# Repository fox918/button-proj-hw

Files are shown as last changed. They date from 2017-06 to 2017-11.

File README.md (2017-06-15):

# Hacker Jeopardy Buttons and Mood Lighting Shelf

## Idea

This is a small PCB designed for a NodeMCU v3 to control up to 4 WS2812b LED-Strips.
The goal of the project is to light up hacker jeopardy buttons or to light something with
the ws2812b buttons.

## Considerations:
- care has been taken that at least 2 strips are usable for Lua or Micropython respectively
- There is a jumper to bypass the voltage regulator if the board is directly supplied with 5V

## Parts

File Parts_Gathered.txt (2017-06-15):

== Requirements ==
-12V Power for Matt
-5V for Oliver
-2 Strips for Oliver / 1 for Matt
-1 Button for Oliver

== Power 12V / 5V ==
-Oliver:    Bypass because I got already 5V
-Matt:      12V->5V Linear Regulator
            AZ1117CH-5.0TRG1 in SOT223

== Level Shifter ==
4x Buffer HCT Series, SN74AHCT125DRG4 in SOIC

== Connectors ==
-Oliver: Solder on snap ins
-Matt:   evtl. Mini-XLR

== Proposals ==
SERIES resistor between: Node<->Buffer and Buffer<->Strip
Polyfuse on Input

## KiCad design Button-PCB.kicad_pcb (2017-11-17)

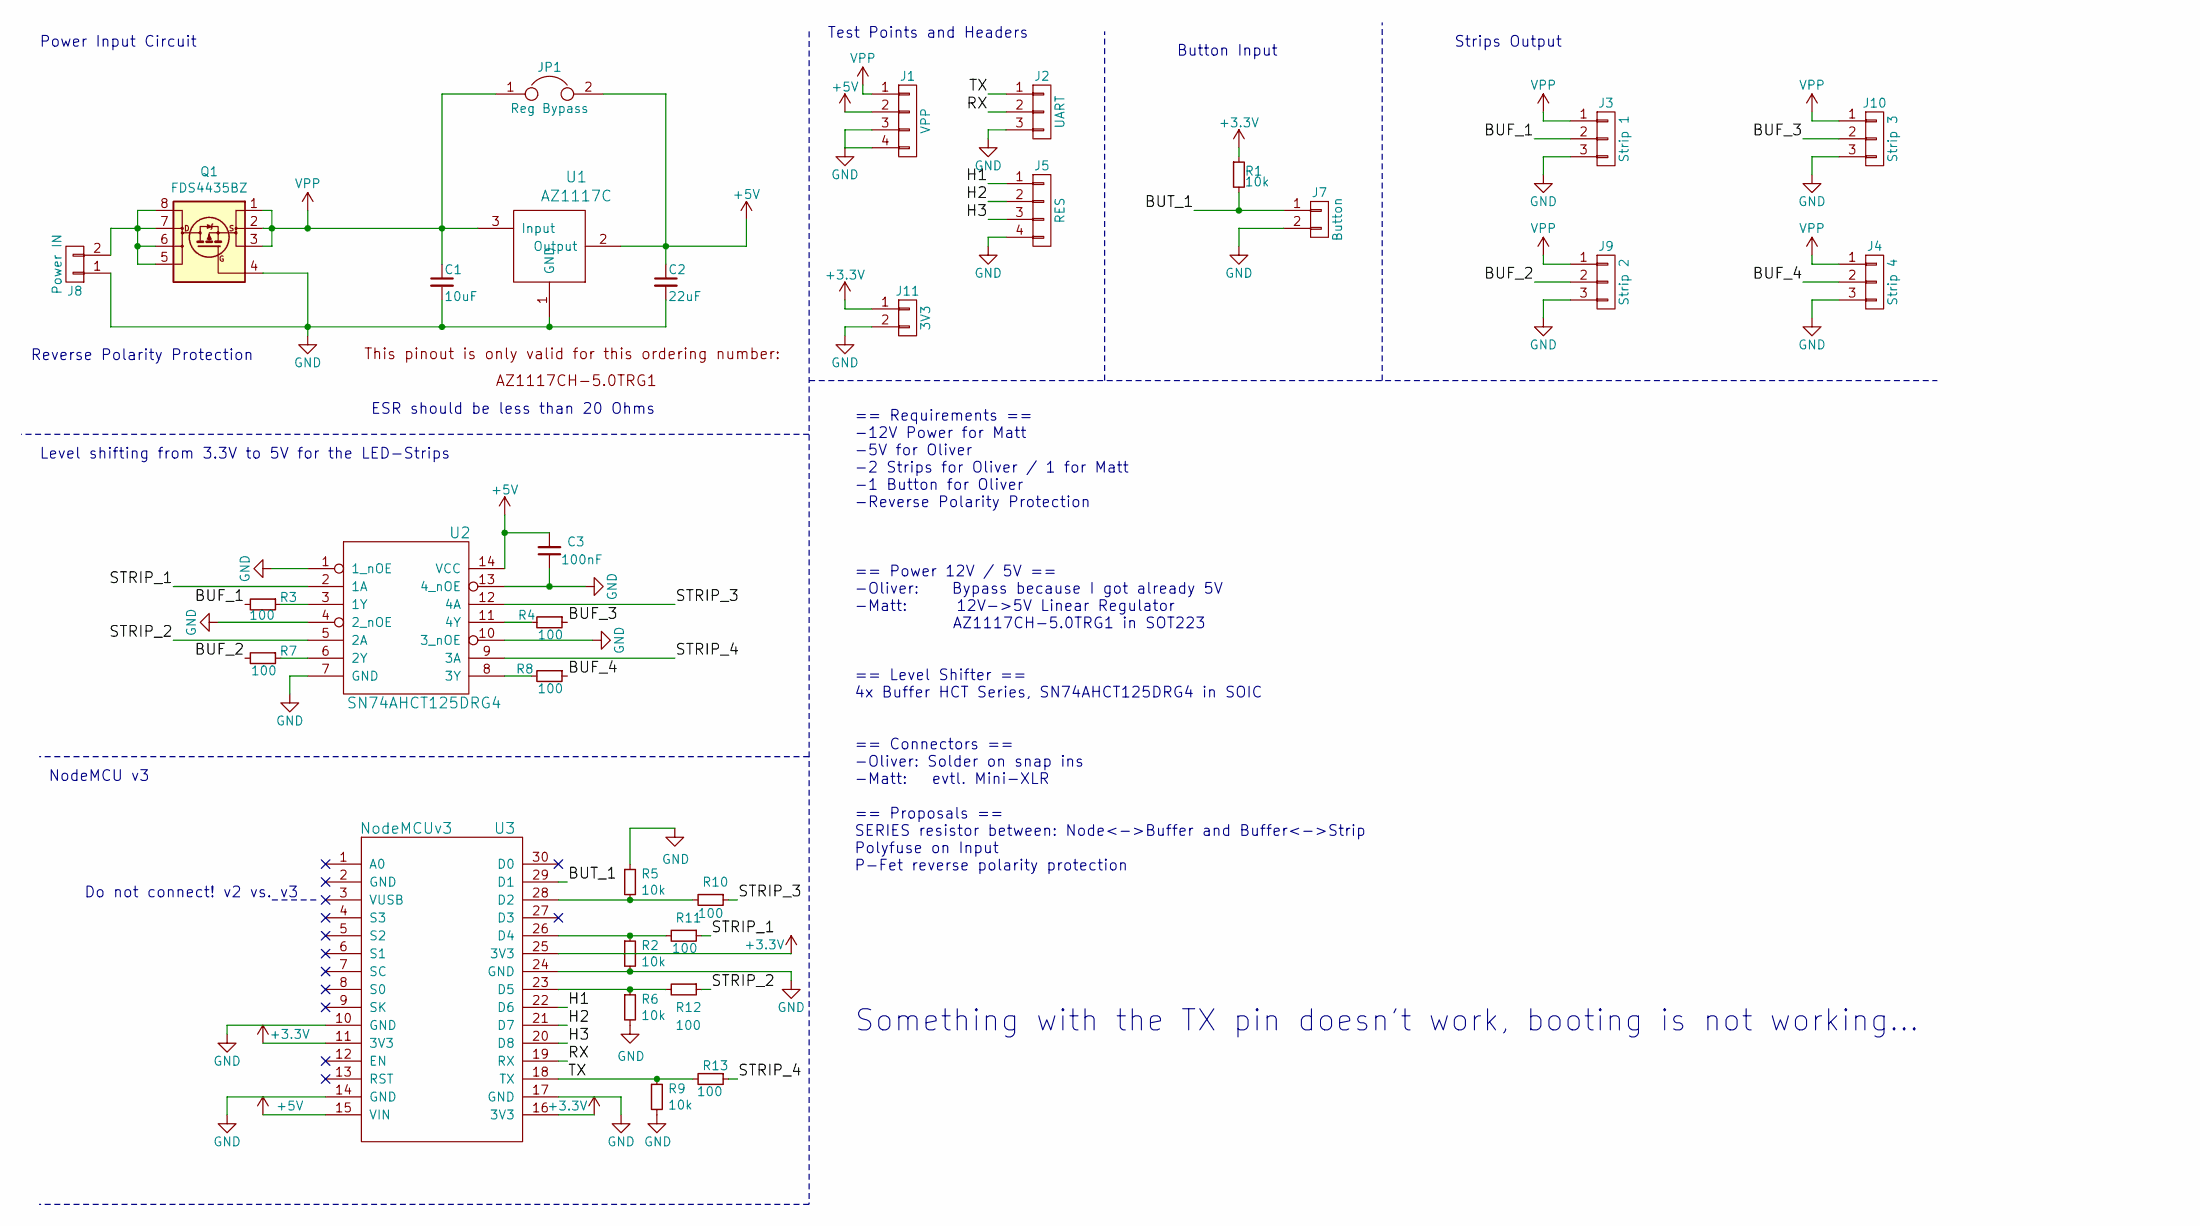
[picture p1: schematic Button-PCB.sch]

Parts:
C1: 10uF; C_0805
C2: 22uF; C_0805
C3: 100nF; C_0805
J1: VPP; Pin_Header_Straight_1x04_Pitch2.54mm
J2: UART; Pin_Header_Straight_1x03_Pitch2.54mm
J3: Strip 1; Pin_Header_Angled_1x03_Pitch2.54mm
J4: Strip 4; Pin_Header_Angled_1x03_Pitch2.54mm
J5: RES; Pin_Header_Straight_1x04_Pitch2.54mm
J7: Button; Pin_Header_Straight_1x02_Pitch2.54mm
J8: Power IN; Pin_Header_Straight_1x02_Pitch2.54mm
J9: Strip 2; Pin_Header_Angled_1x03_Pitch2.54mm
J10: Strip 3; Pin_Header_Angled_1x03_Pitch2.54mm
J11: 3V3; Pin_Header_Straight_1x02_Pitch2.54mm
JP1: Reg Bypass; Pin_Header_Straight_1x02_Pitch2.54mm
Q1: FDS4435BZ; SOIC-8_3.9x4.9mm_Pitch1.27mm
R1, R2, R5, R6, R9: 10k; R_0805
R3, R4, R7, R8, R10, R11, R12, R13: 100; R_0805
U1: AZ1117C; SOT-223-3Lead_TabPin2
U2: SN74AHCT125DRG4; SOIC-14_N
U3: NodeMCUv3; nodemcu_v3

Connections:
+3V3: J11.1, R1.1, U3.11 (3V3), U3.16 (3V3), U3.25 (3V3)
+5V: C2.1, C3.2, J1.2, JP1.2, U1.2 (Output), U2.14 (VCC), U3.15 (VIN)
/BUF_1: J3.2, R3.2
/BUF_2: J9.2, R7.2
/BUF_3: J10.2, R4.1
/BUF_4: J4.2, R8.1
/BUT_1: J7.1, R1.2, U3.29 (D1)
/H1: J5.1, U3.22 (D6)
/H2: J5.2, U3.21 (D7)
/H3: J5.3, U3.20 (D8)
/RX: J2.2, U3.19 (RX)
/STRIP_1: R11.1, U2.2 (1A)
/STRIP_2: R12.1, U2.5 (2A)
/STRIP_3: R10.1, U2.12 (4A)
/STRIP_4: R13.1, U2.9 (3A)
/TX: J2.1, R9.1, R13.2, U3.18 (TX)
GND: C1.2, C2.2, C3.1, J1.3, J1.4, J2.3, J3.3, J4.3, J5.4, J7.2, J8.1, J9.3, J10.3, J11.2, Q1.4 (G), R2.2, R5.1, R6.2, R9.2, U1.1 (GND), U2.1 (1_nOE), U2.4 (2_nOE), U2.7 (GND), U2.10 (3_nOE), U2.13 (4_nOE), U3.10 (GND), U3.14 (GND), U3.17 (GND), U3.24 (GND)
unnamed: J8.2, Q1.5 (D), Q1.6 (D), Q1.7 (D), Q1.8 (D)
unnamed: R3.1, U2.3 (1Y)
unnamed: R4.2, U2.11 (4Y)
unnamed: R7.1, U2.6 (2Y)
unnamed: R8.2, U2.8 (3Y)
unnamed: R5.2, R10.2, U3.28 (D2)
unnamed: R2.1, R11.2, U3.26 (D4)
unnamed: R6.1, R12.2, U3.23 (D5)
VPP: C1.1, J1.1, J3.1, J4.1, J9.1, J10.1, JP1.1, Q1.1 (S), Q1.2 (S), Q1.3 (S), U1.3 (Input)

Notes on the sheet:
== Requirements == -12V Power for Matt -5V for Oliver -2 Strips for Oliver / 1 for Matt -1 Button for Oliver -Reverse Polarity Protection == Power 12V / 5V == -Oliver: Bypass because I got already 5V -Matt: 12V->5V Linear Regulator AZ1117CH-5.0TRG1 in SOT223 == Level Shifter == 4x Buffer HCT Series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
Strips Output
Button Input
Test Points and Headers
ESR should be less than 20 Ohms
Power Input Circuit
Do not connect! v2 vs. v3
Reverse Polarity Protection
Level shifting from 3.3V to 5V for the LED-Strips
NodeMCU v3
Something with the TX pin doesn't work, booting is not working...

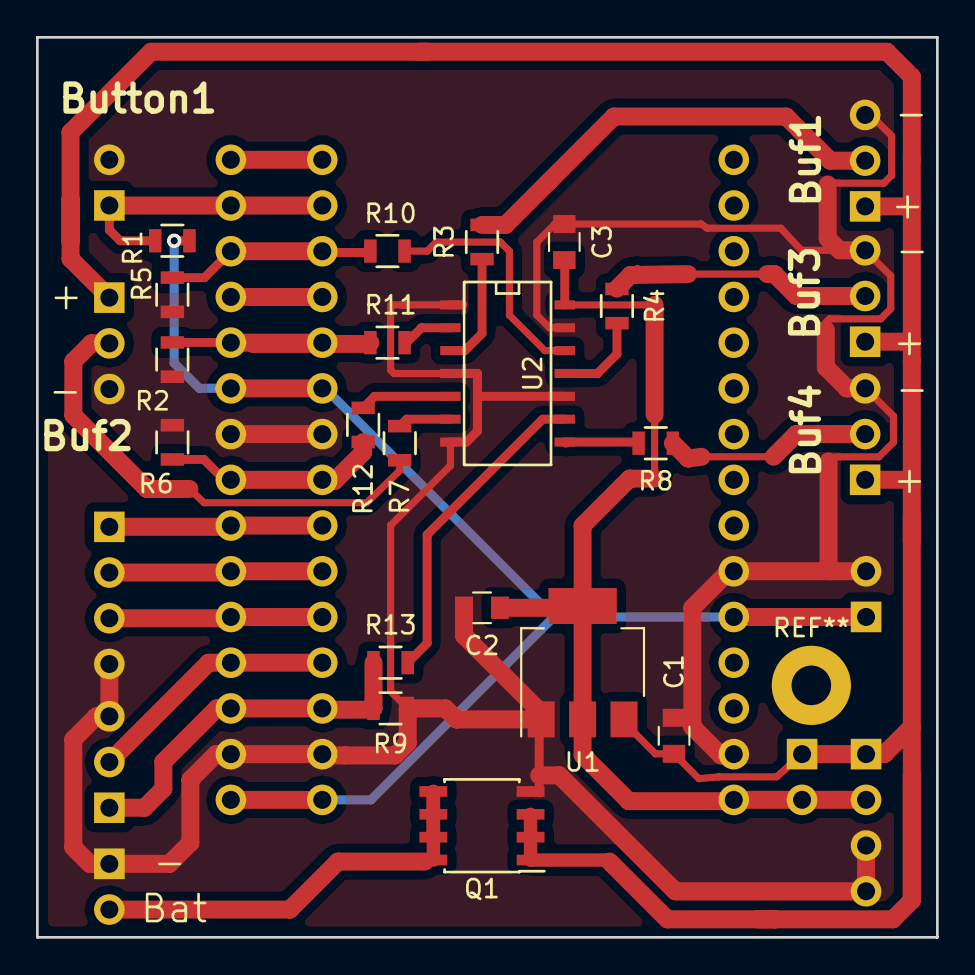
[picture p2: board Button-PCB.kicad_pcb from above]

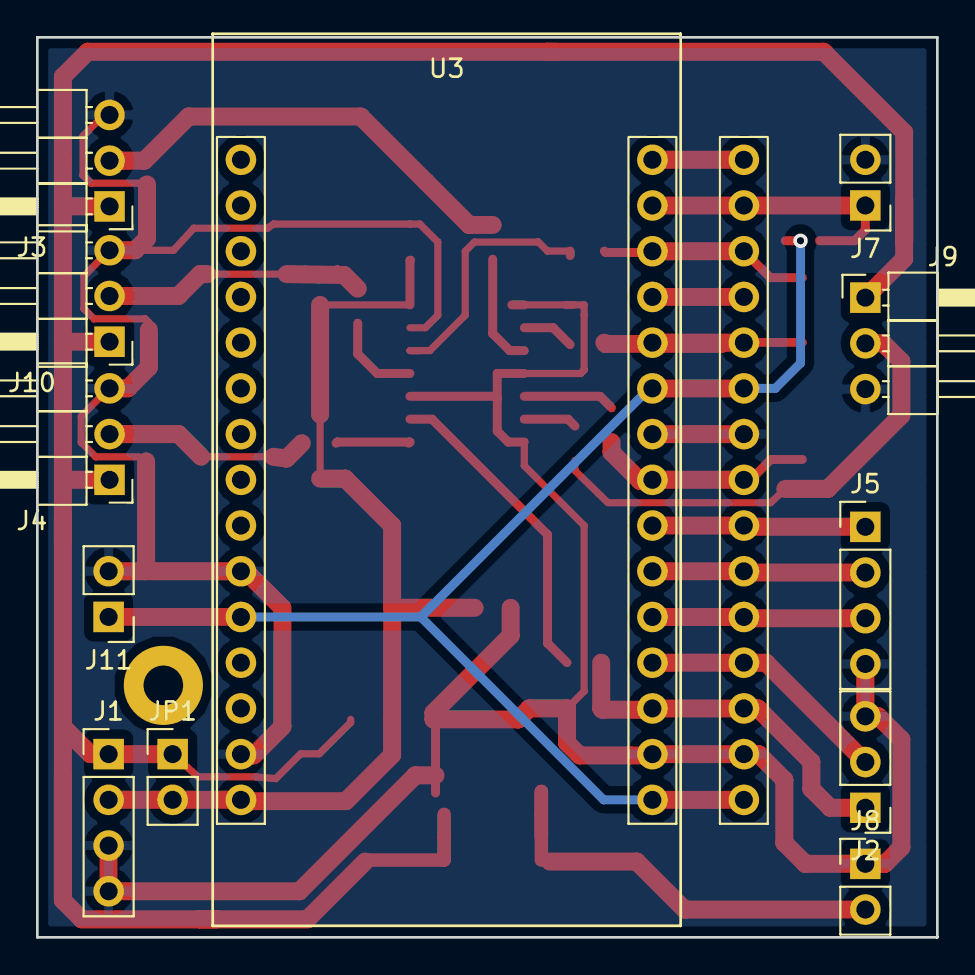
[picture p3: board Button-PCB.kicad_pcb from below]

Board: 2 copper layers, 50.0 x 50.0 mm, 31 parts (12 on the bottom side), 26 nets.

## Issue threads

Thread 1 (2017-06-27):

Improvements

fox918, 2017-06-27:
Thoughts:

- the 5 V jumper should be a solder bridge IMO
- Status LEDs on the board would be handy
- there's probably no point in connecting all the 3.3 V pins of the module
- Something else I wanted to tell you that I can't recall currently
- I have barely tested it

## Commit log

2017-06-17 Removing note on caps for the nodemcu
    Caps are probably not required across the rails of the nodemcu because:
    1. The capacitor at the output of the regulator takes care of some
    decoupling already.
    2. There's probably a sufficient amount of capacitance on the nodemcu
    board already.
    [Button-PCB.sch]
2017-06-17 Stop tracking Button-PCB.bak file
2017-06-17 Adding missing wire between STRIP label and termination resistors.
    [Button-PCB.sch]
2017-06-17 Adding 100k pull-down resistors to buffer input.
    [Button-PCB.sch]
2017-06-17 Moving series termination resistors from sink (buf) to source (esp)
    [Button-PCB.sch]
2017-06-17 Value of series termination resistors: 100R
    [Button-PCB.sch]
2017-06-17 Reducing pull-down resistor values from 100k to 10k
    A 10k resistor is already used as pull-up for the button. This change
    keeps the number of distinct resistor values low.
    [Button-PCB.sch]
2017-06-17 Moving series termination of strips to source and assigning 100R
    [Button-PCB.sch]
2017-06-17 Minor schematic rework to tie up loose ends. No functional changes.
    [Button-PCB.sch]
2017-06-17 Initial part annotation
    [Button-PCB.sch]
2017-06-17 Assigning footprints for resistors (0805), caps (0805) and buffer (SOIC-N)
    [Button-PCB.sch]
2017-06-17 Swap out FDS4435BZ symbol with one of the correct pinout for the SOIC-8 footprint.
    [Button-PCB.sch]
2017-06-17 Adding GND pin to UART and RES connectors.
    [Button-PCB.sch]
2017-06-17 Using standard 2.54" headers for all connectors for now. Will change later.
    [Button-PCB.sch]
2017-06-18 Initial version of NodeMCU footprint. Unchecked!
    With 3d model of socket strips, rough outline and fp-lib-table entry.
2017-06-18 Fixing pin numbering in NodeMCU footprint.
2017-06-18 Assigning NodeMCU footprint
    [Button-PCB.sch]
2017-06-18 AZ1117CH-5.0TRG1 symbol fix: Swapped GND pin number and name.
2017-06-18 Swapping STRIP_2 and STRIP_4 nodes for easier routing
    [Button-PCB.sch]
2017-06-18 Relocating pull-down resistors for easier routing
    [Button-PCB.sch]
2017-06-24 Fixed assignment of footprint for AZ1117C part.
    [Button-PCB.sch]
2017-06-24 Annotate regulator (U1)
    [Button-PCB.sch]
2017-06-27 Rename nets so that strip 3 drives buf 3 instead of buf 4.
    [Button-PCB.sch]
2017-08-03 Initial board layout. Very crude, see ticket for necessary changes.
    [Button-PCB.kicad_pcb]
2017-11-17 hacking bugs
    [Button-PCB-B.Cu.gbl, Button-PCB-B.Mask.gbs, Button-PCB-B.Paste.gbp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]
